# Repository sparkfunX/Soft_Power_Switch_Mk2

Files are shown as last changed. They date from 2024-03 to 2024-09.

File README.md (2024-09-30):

SparkX Soft Power Switch Mk2
===================================================

SparkX Soft Power Switch Mk2 (SPX-25365) (https://www.sparkfun.com/products/25365)

[*SparkX Soft Power Switch Mk2 (SPX-25365)*](https://www.sparkfun.com/products/25365)

The Soft Power Switch Mk2 is a passive, hard on/off switch with software feedback and control. In other words, it's like the on/off switch on a laptop. A simple press will turn the system on. Another press can (with MCU intervention) turn off the system. And if things go really wrong, pressing and holding the button for ~10 seconds will force a power-down. If you're building something with an enclosed battery and need a good power button, this is the board you need.

The [Mk1 Soft Power Switch](https://www.sparkfun.com/products/17870) is great, but we do see occasional issues caused by component tolerances or the operating temperature. Mk2 is based on an application note by Texas Instruments, and is a completely digital design. It is based around a 74LVC1G175 D-type flip-flop - remember those?! - and is insensitive to temperature and component variation. It also includes improvements like: an over-current self-resetting 2A fuse; input and output LEDs. This version has JST 2mm battery connectors, but we also have a version with [USB-C](https://www.sparkfun.com/products/25366) connectors.

The PUSH pin can act as an output to a microcontroller indicating the state of the power button (high = not pressed, low = user is pressing power button). This can be used as an input to your firmware to begin to shut down before power is lost. PUSH is an open-drain output and requires a pull-up. Alternatively, the OFF pin can be driven **high** by the system forcing fast power off via software. (For Mk1, the Fast Off pin was driven **low**.)

The most common use case is something like this:

* Microcontroller begins running code and checks to see if the power button is still being pressed for X milliseconds.
* If not, it's just a tap, go back to sleep.
* If yes, power up and run normal program.

Later...

* User presses power button in normal program
* If power button is pressed for <X milliseconds, it's just a tap, ignore.
* If power button is pressed for >X milliseconds, it's time to power down.

The wake-up and power-down times can be tweaked for your own user experience but we found 500ms for power up and 2s for power down work really well.

If needed, pads are provided for a larger, external button.

The Soft Power Switch supports battery charging. If the target device has onboard LiPo charging, current can be passed back through the switch circuit and charge the battery.

<b>Heads up!</b> The Mk2 Soft Power Switch works up to 5.5V only. (Mk1 is good up to 12V.)

Pros:

* Very low quiescent current: <1µA @ 3.75V, with VIN LED disabled
* Hard override power down in case your microcontroller loses its mind
* PUSH and OFF pins can be connected to a microcontroller
* Supports battery charging

Cons:

* Limited to 2A continuous, 4A peak (fuse protected)
* No AC loads

Features
-------------------
* Input voltage: 5.5V maximum, 1.8V minimum
* Maximum current draw: 2A continuous, 4A peak (fuse protected)
* Very low quiescent current: <1µA @ 3.75V, with VIN LED disabled
* Hard override: push and hold the button for ~10 seconds
* Supports battery charging
* 1" x 1" PCB
* LEDs: VIN and VOUT (can be disabled if desired)
* Breakouts:
    * GND, VIN, VOUT
    * BTN: if desired, connect an external button between BTN and GND
    * PUSH: open-drain output, requires pull-up, low indicates button is pushed
    * OFF: drive high to turn the output off

Repository Contents
-------------------
* **/Examples** - Example sketches demonstrating how to read and control the switch
* **/Hardware** - KiCad design files
* **LICENSE.md** - license information

Product Versions
----------------
* [SPX-25365](https://www.sparkfun.com/products/25365) - Original SparkX Release.

License Information
-------------------

This product is _**open source**_!

Please review the LICENSE.md file for license information.

If you have any questions or concerns on licensing, please contact technical support on our [SparkFun forums](https://forum.sparkfun.com/viewforum.php?f=123).

Distributed as-is; no warranty is given.

- Your friends at SparkFun.

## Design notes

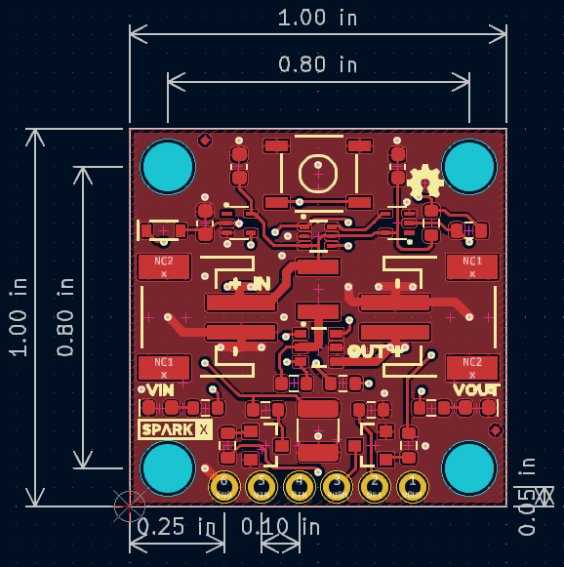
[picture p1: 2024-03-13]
Hardware/Dimensions.png

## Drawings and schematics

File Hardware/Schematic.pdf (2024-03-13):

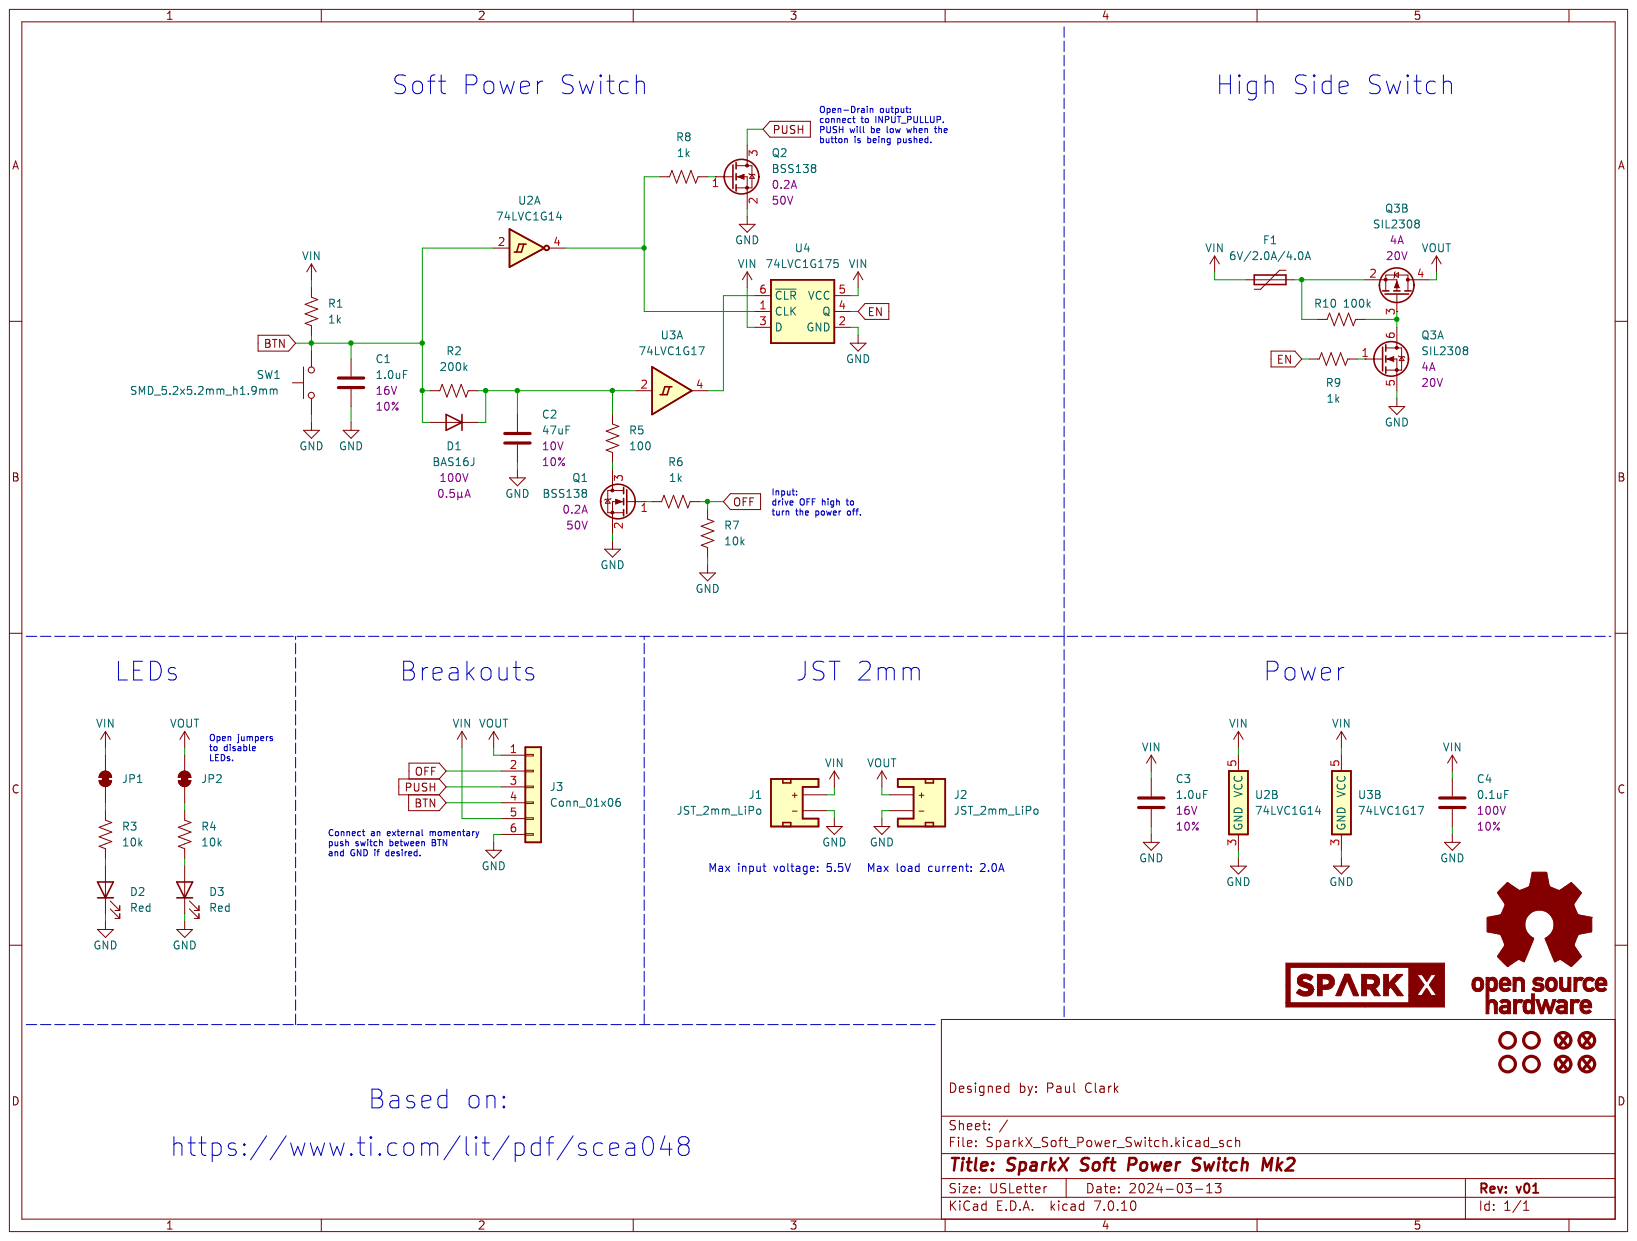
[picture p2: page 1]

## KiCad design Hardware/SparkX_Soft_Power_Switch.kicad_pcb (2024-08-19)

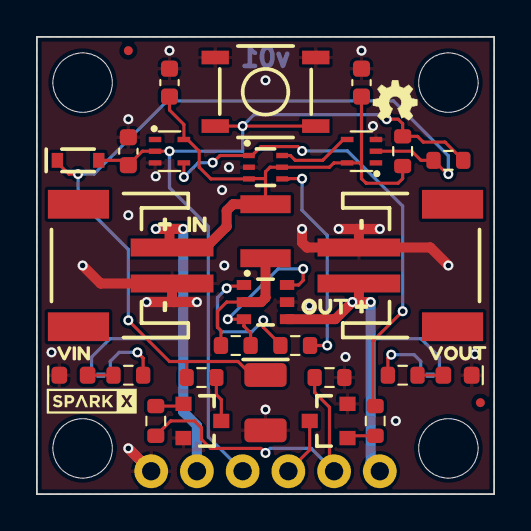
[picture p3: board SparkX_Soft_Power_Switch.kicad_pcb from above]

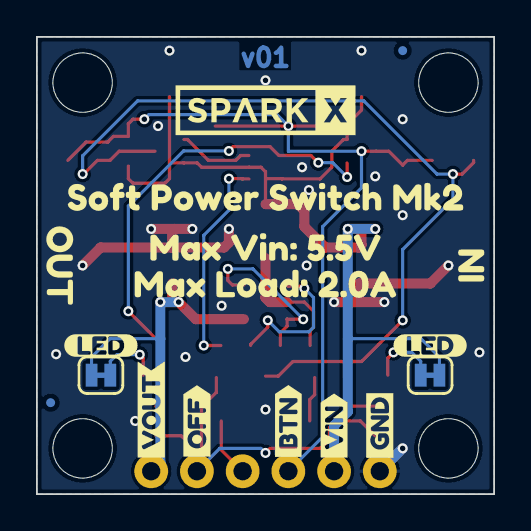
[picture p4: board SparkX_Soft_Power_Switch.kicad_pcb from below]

Board: 2 copper layers, 25.4 x 25.4 mm, 60 parts (16 on the bottom side), 20 nets.

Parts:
C1, C3: 1.0uF; C_0603_1608Metric
C2: 47uF; EIA-3528
C4: 0.1uF; C_0603_1608Metric
D1: BAS16J; SOD-323
D2, D3: Red; LED_0603_1608Metric_Red
F1: 6V/2.0A/4.0A; 1210
FID1, FID2, FID3, FID4: Fiducial_0.5mm; Fiducial_0.5mm_Mask1mm
G3: OSHW_Logo; Creative_Commons_License
J1, J2: JST_2mm_LiPo; JST_SMD_2.0mm-2
J3: Conn_01x06; 1x06
JP1, JP2: Jumper_2_NC_Trace
Q1, Q2: BSS138; SOT23-3
Q3: SIL2308; SOT23-6-Tight
R1, R6, R8, R9: 1k; R_0603_1608Metric
R2: 200k; R_0603_1608Metric
R3, R4, R7: 10k; R_0603_1608Metric
R5: 100; R_0603_1608Metric
R10: 100k; R_0603_1608Metric
Ref**: Val**; OSHW_Logo_2.5mm
ST1, ST2, ST3, ST4: Stand_off; Standoff
SW1: SMD_5.2x5.2mm_h1.9mm; Push_SMD_5.2x5.2mm_h1.9mm
U2: 74LVC1G14; SOT-353
U3: 74LVC1G17; SOT-353
U4: 74LVC1G175; SOT-323
kibuzzard-65F04F60, kibuzzard-65F04F60#2: G***; kibuzzard-65F04F60
kibuzzard-65F04FCA, kibuzzard-65F04FCA#2: G***; kibuzzard-65F04FCA
kibuzzard-65F053F1: G***; kibuzzard-65F053F1
kibuzzard-65F054C3, kibuzzard-65F054C3#2: G***; kibuzzard-65F054C3
kibuzzard-65F056D8: G***; kibuzzard-65F056D8
kibuzzard-65F056F7: G***; kibuzzard-65F056F7
kibuzzard-65F174FD: G***; kibuzzard-65F174FD
kibuzzard-65F0543A: G***; kibuzzard-65F0543A
kibuzzard-65F0634B: G***; kibuzzard-65F0634B
kibuzzard-65F0636B: G***; kibuzzard-65F0636B
kibuzzard-65F1758C: G***; kibuzzard-65F1758C
kibuzzard-65F05416: G***; kibuzzard-65F05416
kibuzzard-65F05472: G***; kibuzzard-65F05472
kibuzzard-65F05495: G***; kibuzzard-65F05495
kibuzzard-65F05604: G***; kibuzzard-65F05604
kibuzzard-65F05628: G***; kibuzzard-65F05628
kibuzzard-65F05644: G***; kibuzzard-65F05644

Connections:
BTN: C1.1, D1.A, J3.4, R1.2, R2.2, SW1.2, U2.2
EN: R9.2, U4.4 (Q)
GND: C1.2, C2.2, C3.2, C4.2, D2.1 (K), D3.1 (K), J1.1 (-), J2.1 (-), J3.6, Q1.2 (S), Q2.2 (S), Q3.5 (S), R7.2, SW1.1, U2.3 (GND), U3.3 (GND), U4.2 (GND)
unnamed: C2.1, D1.C, R2.1, R5.1, U3.2
unnamed: D2.2 (A), R3.2
unnamed: D3.2 (A), R4.2
unnamed: JP1.1 (A), R3.1
unnamed: JP2.1 (A), R4.1
unnamed: Q1.3 (D), R5.2
unnamed: Q1.1 (G), R6.1
unnamed: Q2.1 (G), R8.2
unnamed: Q3.3 (G), Q3.6 (D), R10.1
unnamed: Q3.1 (G), R9.1
unnamed: F1.1, Q3.2 (1), R10.2
unnamed: R8.1, U2.4, U4.1 (CLK)
unnamed: U3.4, U4.6 (~CLR)
OFF: J3.2, R6.2, R7.1
PUSH: J3.3, Q2.3 (D)
VIN: C3.1, C4.1, F1.2, J1.2 (+), J3.5, JP1.2 (B), R1.1, U2.5 (VCC), U3.5 (VCC), U4.3 (D), U4.5 (VCC)
VOUT: J2.2 (+), J3.1, JP2.2 (B), Q3.4 (D)

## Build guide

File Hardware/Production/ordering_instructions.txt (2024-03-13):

Ordering Instructions:
Panel dimensions: 194.50 x 142.70 mm.
Solder Mask: Black
Silkscreen: White
Layers: 2
Finish: HASL
Thickness: 1.6mm
Copper Weight: 1oz
Minimum track width: 0.18mm (7.00mil)
Minimum via drill: 0.30mm (11.81mil)

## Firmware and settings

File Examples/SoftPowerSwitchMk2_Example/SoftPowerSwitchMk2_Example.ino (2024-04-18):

/*
  Control the power to a system using the SparkFun Soft Power Switch Mk2
  By: Nathan Seidle
  Adapted by: Paul Clark
  SparkFun Electronics
  Date: March 14th, 2024
  License: MIT. See license file for more information

  This example assumes the OFF pin is connected.

  A simple tap of the power button will turn on the system. If the power button is not being pressed 
  (accidental tap) the system will turn off after ~20ms. If the system turns on and sees the power 
  button held for 0.5s, it will begin normal operation.

  During normal system operation, if user presses the power button for 2s, the system
  will shut down. This means the power button can also be used as a general 'select' button as
  long as user doesn't hold button for more than 2s.

  This example will output serial states. If you are powering your board over a USB connection then
  the power button can't do its job. We did our testing by connecting the TX and GND pins of a RedBoard to 
  an external USB to Serial adapter. That way the battery + Soft Power Switch could control power
  to the board.  
*/

//Hardware connections - GPIO pins (change these as required)
int _PUSH = 14; // Connect this GPIO to the PUSH breakout pad
int _OFF = 32; // Connect this GPIO to the OFF breakout pad

int STAT_LED = LED_BUILTIN;

unsigned long powerPressedStartTime = 0;

int debounceDelay = 20;

//Uncomment the following line to turn on shutdown time measurements
//#define PRINT_TIMER_OUTPUT

void setup()
{
  Serial.begin(115200);
  Serial.println("Soft Power Switch Mk2 example");

  pinMode(_PUSH, INPUT_PULLUP);

  //User has pressed the power button to turn on the system
  //Was it an accidental bump or do they really want to turn on?
  //Let's make sure they continue to press for two seconds
  Serial.print("Initial power on check");
  powerPressedStartTime = millis();
  while (digitalRead(_PUSH) == LOW)
  {
    //Wait for user to stop pressing button.
    //What if user has left something heavy pressing the power button?
    //The soft power switch will automatically turn off the system! Handy.
    delay(100);

    if ((millis() - powerPressedStartTime) > 500)
      break;
    Serial.print(".");
  }
  Serial.println();

  if ((millis() - powerPressedStartTime) < 500)
  {
    Serial.println("Power button tap. Returning to off state. Powering down");
    powerDown();
  }

  Serial.println("User wants to turn system on!");
  powerPressedStartTime = 0; //Reset var to return to normal 'on' state

  //Here we display something to user indicating system is on and running
  //For example an external display or LED turns on
  pinMode(STAT_LED, OUTPUT);
  digitalWrite(STAT_LED, HIGH);

  Serial.println("Press 'r' to enter infinite loop to test power-down override");
  Serial.println("Press 'z' to do a powerdown");
  Serial.println("Press and hold power button for 2s to do a powerdown");

  while (Serial.available()) // Flush the Serial RX buffer
    Serial.read();
}

void loop()
{
  if (Serial.available())
  {
    char incoming = Serial.read();

    if (incoming == 'z')
    {
      Serial.println("Power down");
      powerDown();
    }
    else if (incoming == 'r')
    {
      Serial.println("System locked. Now hold power button to force power down without using software");

      //Here we wait for user press button so we can time it
      while (digitalRead(_PUSH) == HIGH)
        delay(1);

      powerPressedStartTime = millis();
      Serial.println("Doing nothing, waiting for power override to kick in");
      while (1)
      {
#ifdef PRINT_TIMER_OUTPUT
        Serial.println(millis() - powerPressedStartTime);
#endif
        delay(1);

        if(digitalRead(_PUSH) == HIGH) break;
      }
      Serial.println("User released button before forced powered could complete. Try again, but hold power button for 10s");
      powerPressedStartTime = 0; //Reset var to return to normal 'on' state
    }
  }

  if (digitalRead(_PUSH) == LOW && powerPressedStartTime == 0)
  {
    //Debounce check
    delay(debounceDelay);
    if (digitalRead(_PUSH) == LOW)
    {
      Serial.println("User is pressing power button. Start timer.");
      powerPressedStartTime = millis();
    }
  }
  else if (digitalRead(_PUSH) == LOW && powerPressedStartTime > 0)
  {
    //Debounce check
    delay(debounceDelay);
    if (digitalRead(_PUSH) == LOW)
    {
      if ((millis() - powerPressedStartTime) > 2000) // Check if button has been held for >= 2 seconds
      {
        Serial.println("Time to power down!");
        powerDown();
      }
    }
  }
  else if (digitalRead(_PUSH) == HIGH && powerPressedStartTime > 0)
  {
    //Debounce check
    delay(debounceDelay);
    if (digitalRead(_PUSH) == HIGH)
    {
      Serial.print("Power button released after ms: ");
      Serial.println(millis() - powerPressedStartTime);
    }
    powerPressedStartTime = 0; //Reset var to return to normal 'on' state
  }
}

//Immediately power down
void powerDown()
{
  //Indicate to user we are shutting down
  digitalWrite(STAT_LED, LOW);

  Serial.println("Pulling OFF high");
  Serial.flush();

  powerPressedStartTime = millis();

  pinMode(_OFF, OUTPUT);
  digitalWrite(_OFF, HIGH); // Pull OFF high to turn the power off

  while (1)
  {
#ifdef PRINT_TIMER_OUTPUT
    Serial.println(millis() - powerPressedStartTime);
#endif
    delay(1);
  }
}

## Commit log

2024-03-13 Change to SIL2308 - for battery charging
    [SparkX_Soft_Power_Switch.kicad_pcb, SparkX_Soft_Power_Switch.kicad_sch]
2024-03-13 Add production files
    [SparkX_Soft_Power_Switch_panelized.GBL, SparkX_Soft_Power_Switch_panelized.GBO, SparkX_Soft_Power_Switch_panelized.GBP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]
2024-03-13 Add PROD_IDs
    [SparkX_Soft_Power_Switch.kicad_pcb, SparkX_Soft_Power_Switch.kicad_sch]
2024-03-13 Update 100R resistor PROD_ID
    [SparkX_Soft_Power_Switch.kicad_pcb, SparkX_Soft_Power_Switch.kicad_sch]
2024-04-21 Update to KiCad 8. Update 47uF cap
    [SparkX_Soft_Power_Switch.kicad_pcb, SparkX_Soft_Power_Switch.kicad_sch]
2024-08-19 Update 3D models
    [SparkX_Soft_Power_Switch.kicad_pcb, SparkX_Soft_Power_Switch.kicad_sch]

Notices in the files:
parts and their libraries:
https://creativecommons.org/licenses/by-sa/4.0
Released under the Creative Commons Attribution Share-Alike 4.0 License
